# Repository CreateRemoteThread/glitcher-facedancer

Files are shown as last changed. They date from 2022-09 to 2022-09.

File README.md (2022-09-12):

# glitcher-facedancer

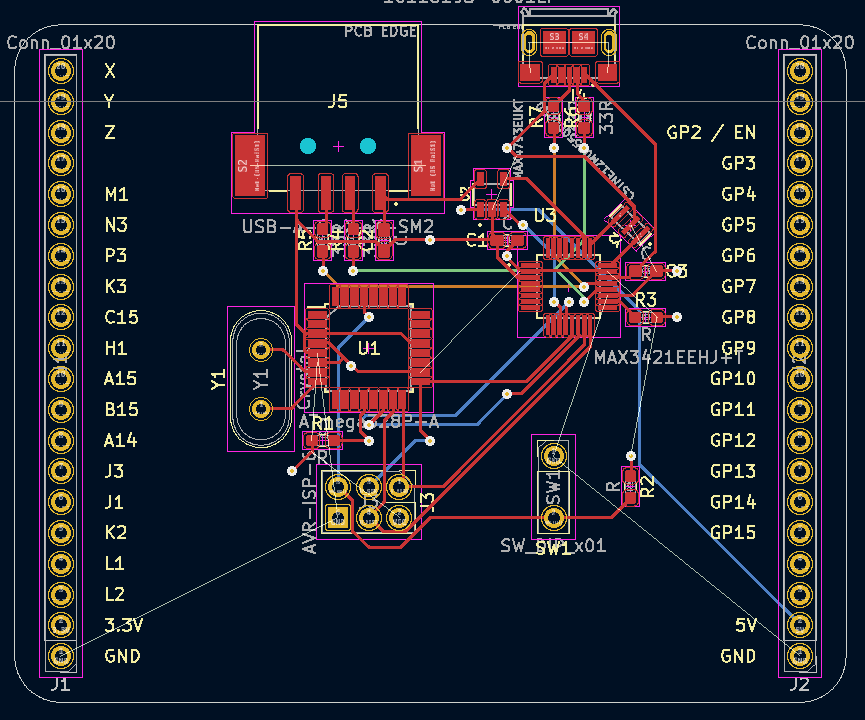
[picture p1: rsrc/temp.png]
pew pew pew


This is a MAX3421 USB addon for [glitcher](https://github.com/createremotethread/glitcher). This is similar in functionality to [facewhisperer](https://github.com/scanlime/facewhisperer) and [facedancer](https://github.com/greatscottgadgets/Facedancer).

The critical improvement is the ability to power cycle the target (MAX4793EUK, 300mA limit) and an on-board microcontroller for experiment automation.

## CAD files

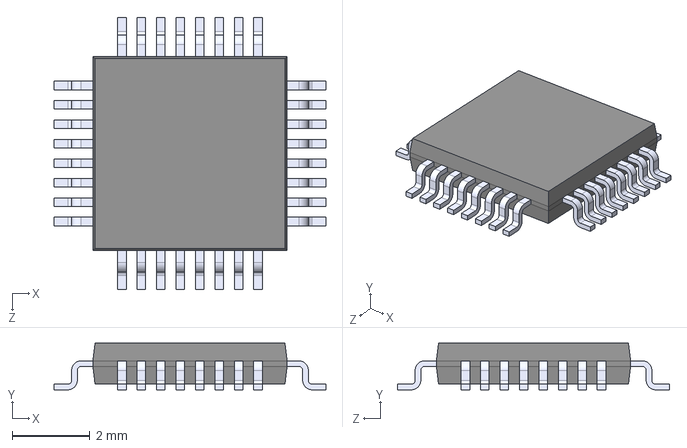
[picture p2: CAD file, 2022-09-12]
rsrc/usbshield/MAX3421EEHJ_T.step
7.00 x 1.20 x 7.00 mm

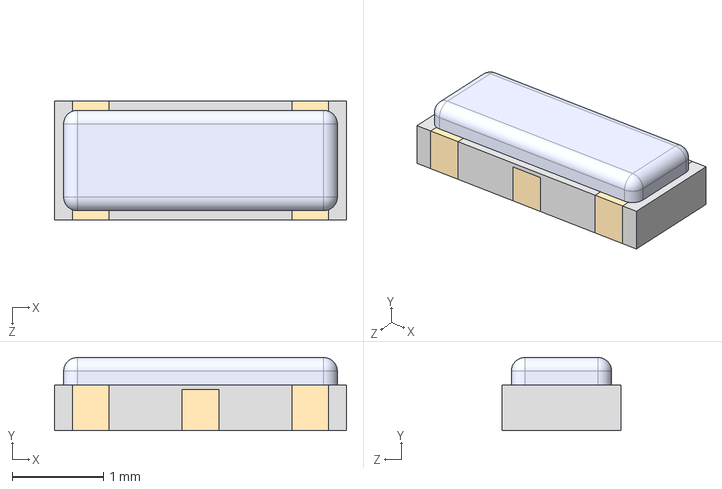
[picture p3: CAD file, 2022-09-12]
rsrc/usbshield/CSTNE12M0G550000R0.step
3.20 x 0.8 x 1.30 mm

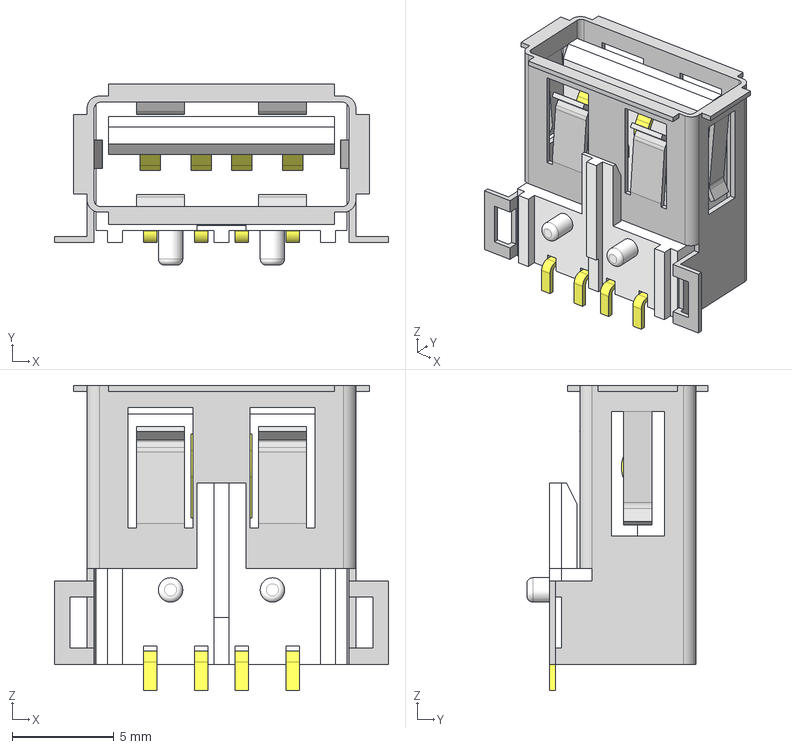
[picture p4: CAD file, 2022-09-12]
rsrc/usbshield/USB-A-S-X-X-SM2.step
16.4 x 8.90 x 15.0 mm
USB-A-S-SM2_P
USB-A-S-W-SM2_B
USB-A-S-SM2_S

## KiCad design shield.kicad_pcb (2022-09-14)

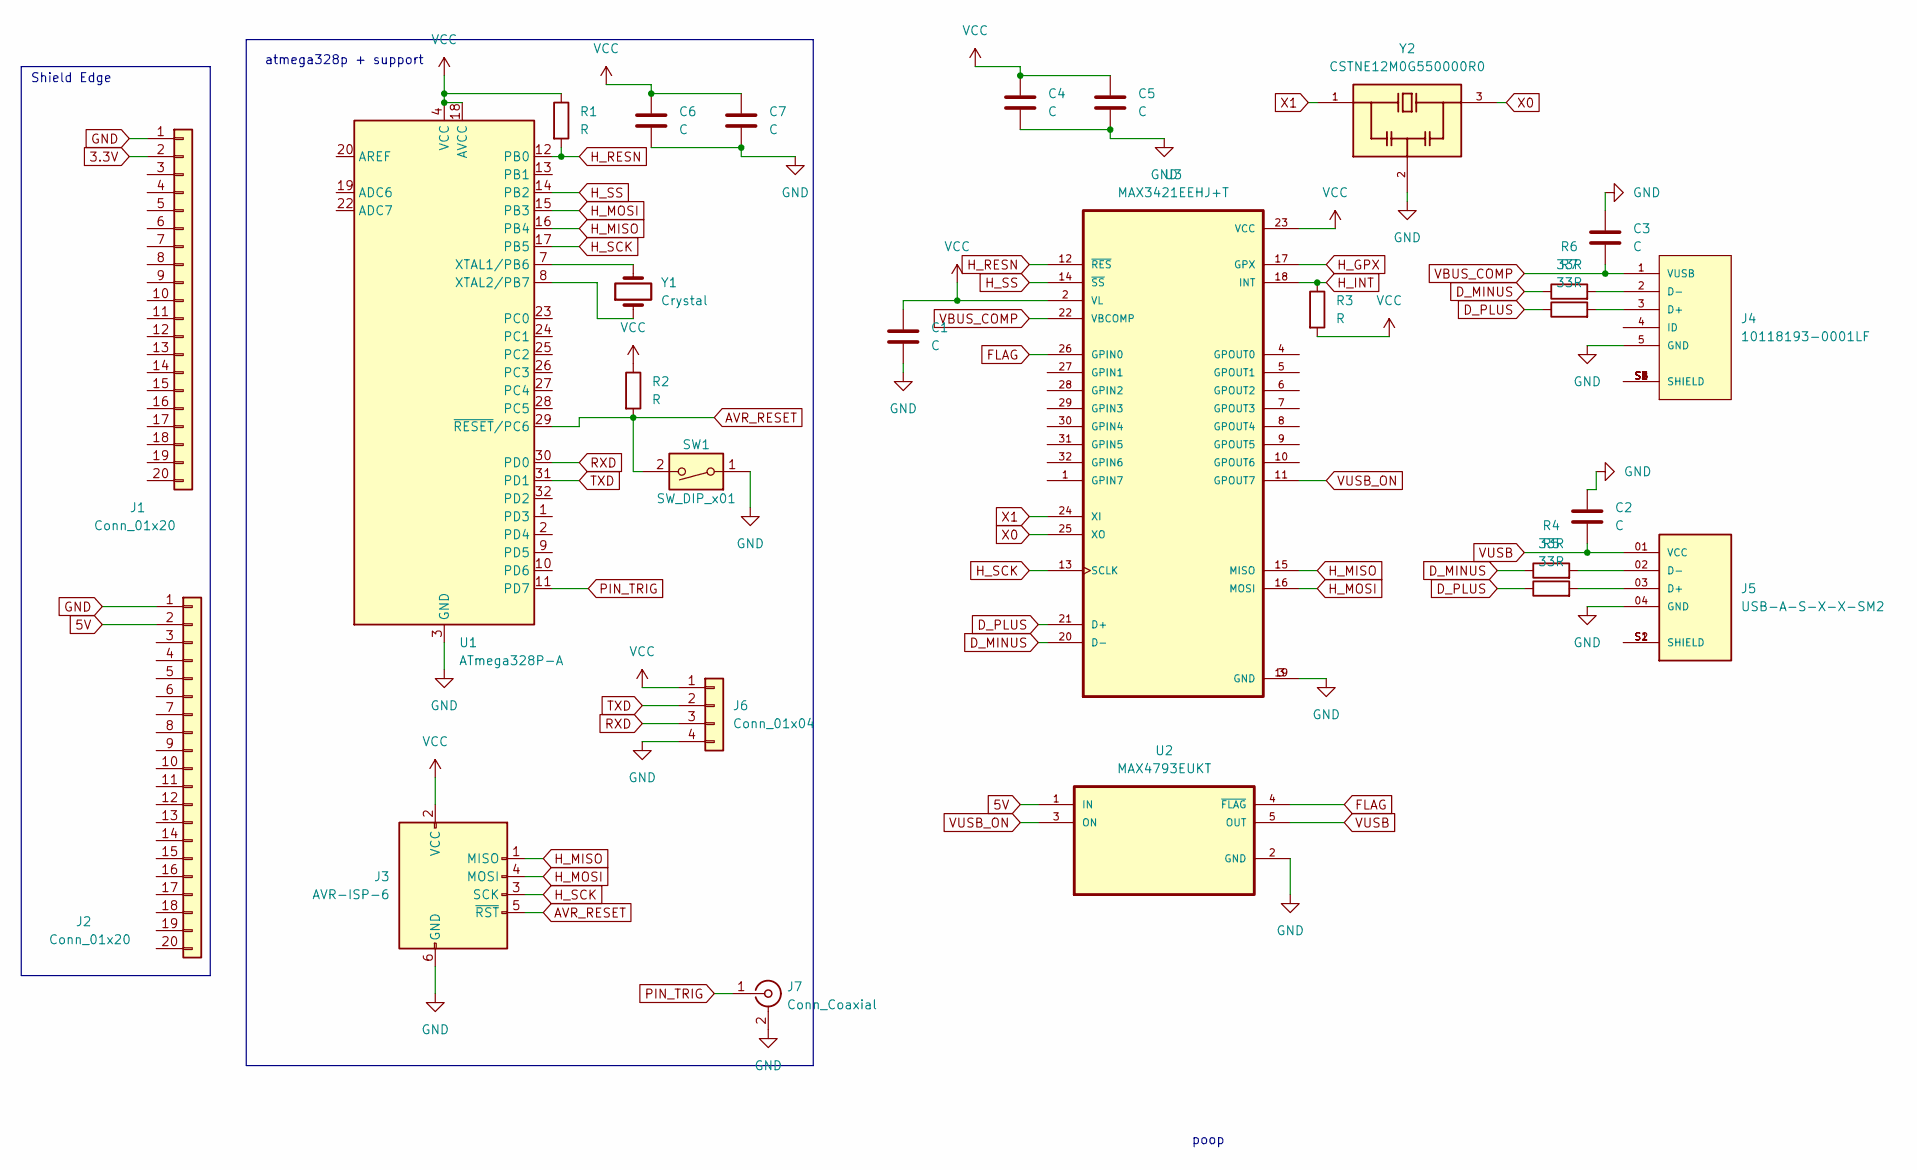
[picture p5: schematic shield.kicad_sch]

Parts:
C1, C2, C3, C4, C5, C6, C7: C; C_0603_1608Metric_Pad1.08x0.95mm_HandSolder
J1, J2: Conn_01x20; PinHeader_1x20_P2.54mm_Vertical
J3: AVR-ISP-6; PinHeader_2x03_P2.54mm_Vertical
J4: 10118193-0001LF; FCI_10118193-0001LF
J5: USB-A-S-X-X-SM2; SAMTEC_USB-A-S-X-X-SM2; PARTREV T
J6: Conn_01x04; PinHeader_1x04_P2.54mm_Vertical
J7: Conn_Coaxial; RF2-04A-T-00-50-G
R1, R2, R3: R; R_0603_1608Metric_Pad0.98x0.95mm_HandSolder
R4, R5, R6, R7: 33R; R_0603_1608Metric_Pad0.98x0.95mm_HandSolder
SW1: SW_DIP_x01; PinHeader_Switch
U1: ATmega328P-A; TQFP-32_7x7mm_P0.8mm
U2: MAX4793EUKT; SOT95P280X145-5N
U3: MAX3421EEHJ+T; QFP50P700X700X120-32N
Y1: Crystal; Crystal_HC49-U_Vertical
Y2: CSTNE12M0G550000R0; OSC_CSTNE12M0G550000R0; PARTREV JGC42-8858A

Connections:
3.3V: J1.2
5V: J2.2, U2.1 (IN)
AVR_RESET: J3.5 (~RST), R2.2, SW1.2, U1.29 (~RESET/PC6)
D_MINUS: R4.1, R6.1, U3.20 (D-)
D_PLUS: R5.1, R7.1, U3.21 (D+)
FLAG: U2.4 (~FLAG), U3.26 (GPIN0)
GND: C1.2, C2.1, C3.1, C4.2, C5.2, C6.2, C7.2, J1.1, J2.1, J3.6 (GND), J4.5 (GND), J5.04 (GND), J6.4, J7.2 (Ext), SW1.1, U1.3 (GND), U1.5 (GND), U1.21 (GND), U2.2 (GND), U3.3 (GND), U3.19 (GND), Y2.2
H_GPX: U3.17 (GPX)
H_INT: R3.1, U3.18 (INT)
H_MISO: J3.1 (MISO), U1.16 (PB4), U3.15 (MISO)
H_MOSI: J3.4 (MOSI), U1.15 (PB3), U3.16 (MOSI)
H_RESN: R1.2, U1.12 (PB0), U3.12 (~RES)
H_SCK: J3.3 (SCK), U1.17 (PB5), U3.13 (SCLK)
H_SS: U1.14 (PB2), U3.14 (~SS)
unnamed: J4.2 (D-), R6.2
unnamed: J4.3 (D+), R7.2
unnamed: J4.S1 (SHIELD), J4.S2 (SHIELD), J4.S3 (SHIELD), J4.S4 (SHIELD), J4.S5 (SHIELD), J4.S6 (SHIELD)
unnamed: J5.02 (D-), R4.2
unnamed: J5.03 (D+), R5.2
unnamed: J5.S1 (SHIELD), J5.S2 (SHIELD)
unnamed: U1.7 (XTAL1/PB6), Y1.2
unnamed: U1.8 (XTAL2/PB7), Y1.1
PIN_TRIG: J7.1 (In), U1.11 (PD7)
RXD: J6.3, U1.30 (PD0)
TXD: J6.2, U1.31 (PD1)
VBUS_COMP: C3.2, J4.1 (VUSB), U3.22 (VBCOMP)
VCC: C1.1, C4.1, C5.1, C6.1, C7.1, J3.2 (VCC), J6.1, R1.1, R2.1, R3.2, U1.4 (VCC), U1.6 (VCC), U1.18 (AVCC), U3.2 (VL), U3.23 (VCC)
VUSB: C2.2, J5.01 (VCC), U2.5 (OUT)
VUSB_ON: U2.3 (ON), U3.11 (GPOUT7)
X0: U3.25 (XO), Y2.3
X1: U3.24 (XI), Y2.1

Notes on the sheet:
atmega328p + support
Shield Edge
poop

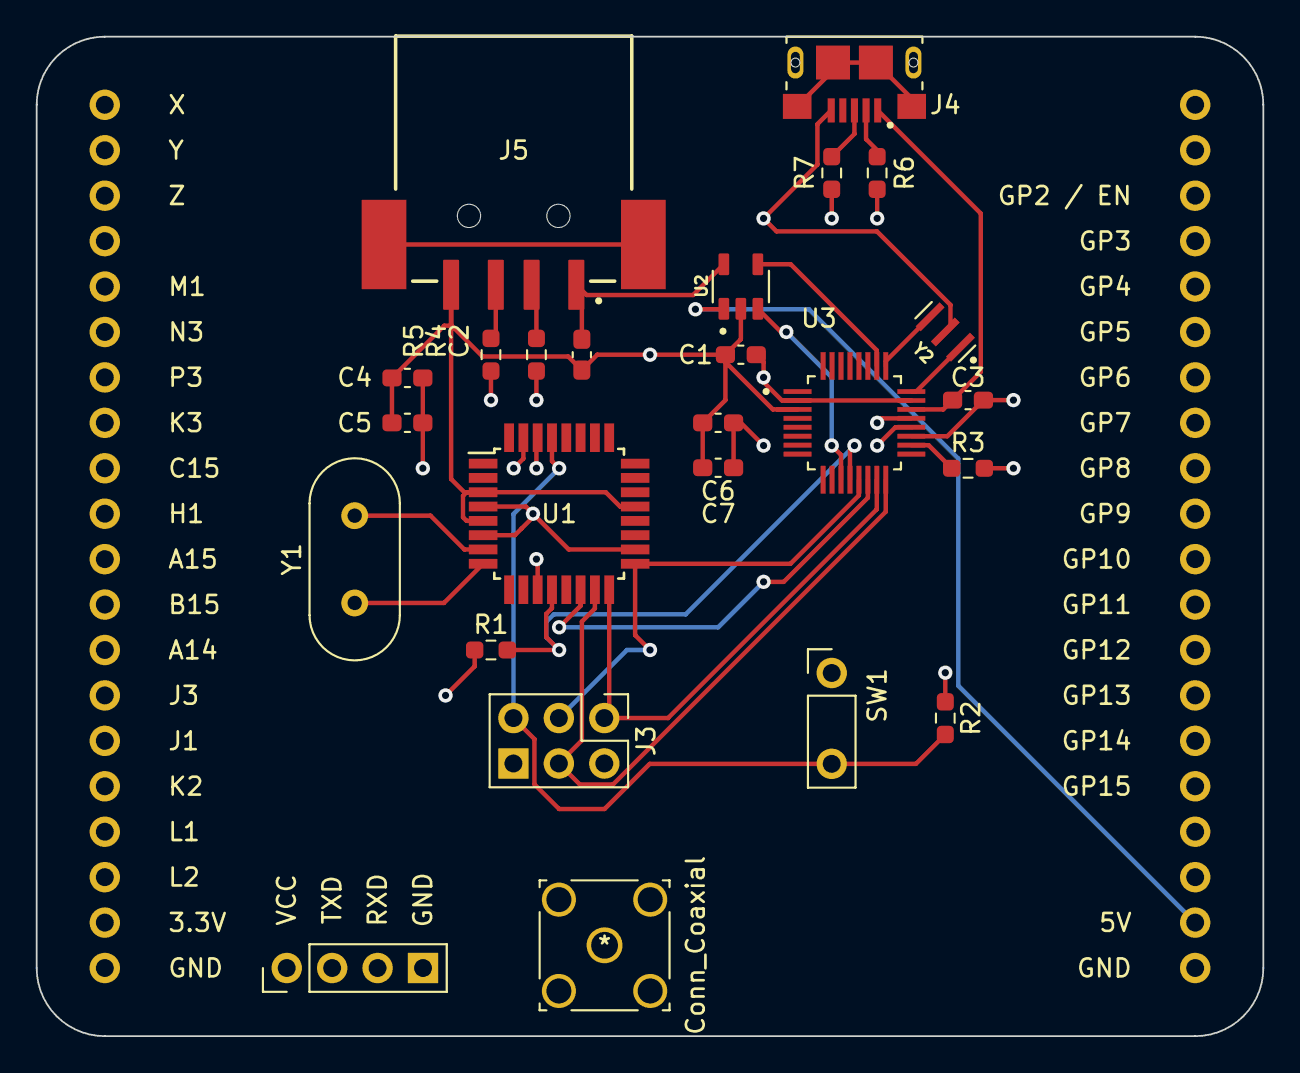
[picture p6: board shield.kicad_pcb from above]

Board: 4 copper layers, 68.6 x 55.9 mm, 27 parts (0 on the bottom side), 29 nets.

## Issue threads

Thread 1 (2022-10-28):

r1 should tie to gnd

CreateRemoteThread, 2022-10-28:
because otherwise the ISP traffic will make the usb chip poop itself

CreateRemoteThread, 2022-10-29:
add 3.3v and 5v power lights, light at switch output

CreateRemoteThread, 2022-10-29:
correct fix is pull up slave select, R1 is fine.

CreateRemoteThread, 2022-10-30:
is there a faster way to "subcontract" the overcurrent protection so we're not reliant on the AVR or the MAX3421 responding in time?

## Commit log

2022-09-12 initial rsrc commit
    [CSTNE12M0G550000R0.step, MAX3421EEHJ_T.step, USB-A-S-X-X-SM2.step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]
2022-09-14 dont let your dreams be memes
    [shield.kicad_pcb, shield.kicad_sch]

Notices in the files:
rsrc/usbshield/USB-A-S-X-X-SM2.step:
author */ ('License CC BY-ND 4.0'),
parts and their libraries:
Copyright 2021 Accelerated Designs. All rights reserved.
